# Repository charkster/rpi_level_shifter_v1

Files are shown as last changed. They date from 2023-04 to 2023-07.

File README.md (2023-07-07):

# rpi_level_shifter_v1
Raspberry Pi level shifter for 10 signals (two boards can fit on the same 40 pin header). Two NVT2010PW ICs are available on a single board, to either level shift from 3.3V to 5V or from 3.3V to 1.8V and 1.2V (jumper selectable). The RPi's 5V is used for the 5V level shift and two on-board LDO regulators are available for shifting levels down to 1.8V or 1.2V. Other voltages can be used, but it is recommended that they not be between 2.6V and 4.3V.  

This board is designed to not fit over-top the RPi board, but rather over the side.

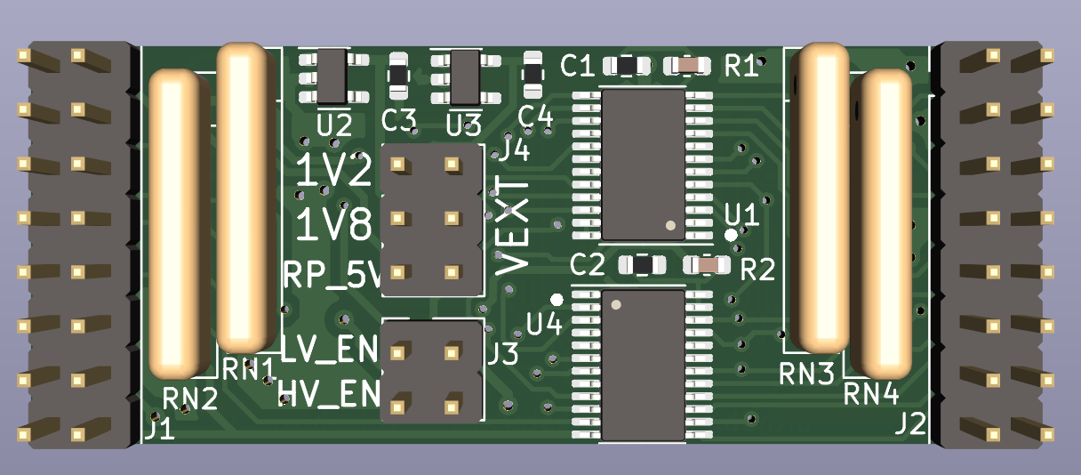
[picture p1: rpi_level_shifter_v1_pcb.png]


Each board needs to have the top-left pin of J1 connected to the 3.3V RPi header pin. One board can service the I2C and UART pins (along with a couple of GPIO) and another board can service SPI pins. BCM GPIO's 13, 16, 19, 20, 21 and 26 are not accessable with this board.

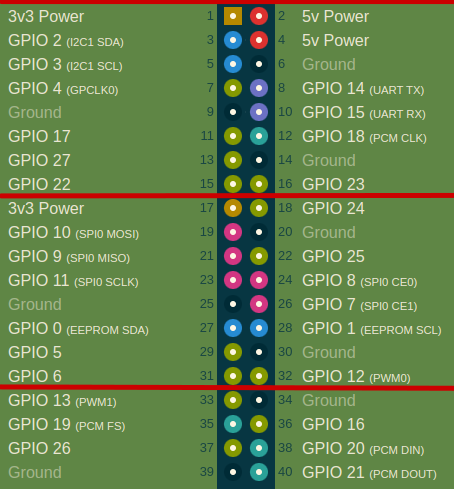
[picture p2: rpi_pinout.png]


Check-out my **PDF** [schematic](https://github.com/charkster/rpi_level_shifter_v1/blob/main/rpi_8x2_v1.pdf) !!

Check-out the CSV [**Bill of Materials**](https://github.com/charkster/rpi_level_shifter_v1/blob/main/rpi_8x2_v1_BOM.csv) !!

**The J3 connector must only have one horizontal jumper!! Either HV_EN or LV_EN, or damage to the RPi pins may occur (you have been warned). Additionally, the J4 connector must only have one horizontal jumper!! The RPI_5V is only available if the level shifter board is at the top of the header, otherwise you will need to jumper wire the 5V to the VEXT pin.**

**UPDATES:**
SPI at 5V is working well to 10MHz with the 1k Ohm pull-up resistors. This matches nicely with the NVT2010PW datasheet. I lowered the pull-up resistors to 500 Ohm and was able to get SPI working at 12MHz. I was not able to run faster than 12MHz at 5V. Power consumption was about 0.5W for both the 0.5k and 1k pull-up resistors.

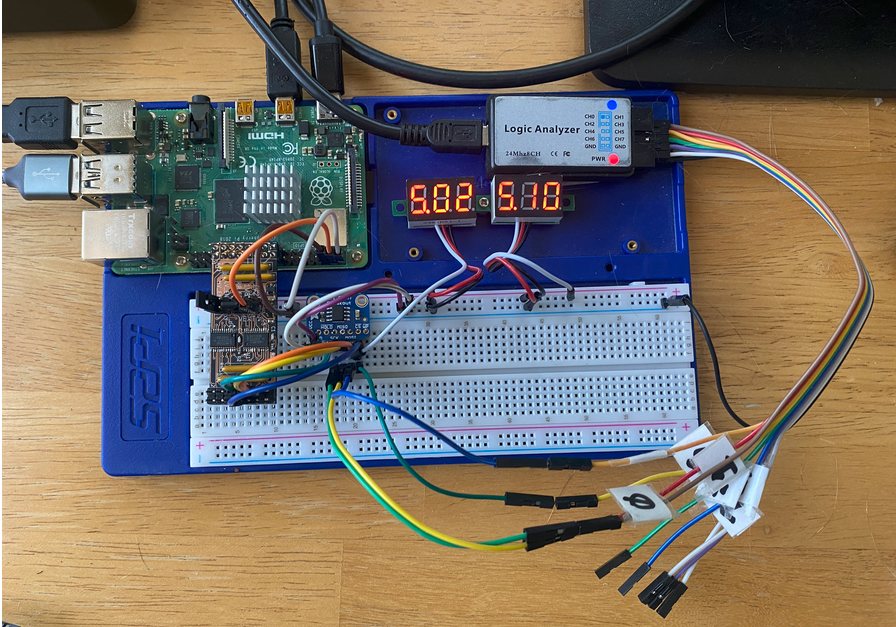
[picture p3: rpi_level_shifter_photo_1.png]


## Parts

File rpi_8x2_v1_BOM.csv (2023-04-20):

Source: | rpi_8x2_v1.kicad_sch
Date: | Wed 19 Apr 2023 10:41:58 PM MST
Tool: | Eeschema 6.0.2+dfsg-1
Generator: | /usr/share/kicad/plugins/bom_csv_grouped_by_value.py
Component Count: | 18
Individual Components:
Item | Qty | Reference(s) | Value | LibPart | Footprint | Datasheet
 |  | C1 | 100pF | Device:C | Resistor_SMD:R_0603_1608Metric | ~
 |  | C2 | 100pF | Device:C | Resistor_SMD:R_0603_1608Metric | ~
 |  | C3 | 10uF | Device:C | Resistor_SMD:R_0603_1608Metric | ~
 |  | C4 | 10uF | Device:C | Resistor_SMD:R_0603_1608Metric | ~
 |  | J1 | Conn_02x08_Odd_Even | Connector_Generic:Conn_02x08_Odd_Even | Connector_PinHeader_2.54mm:PinHeader_2x08_P2.54mm_Vertical | ~
 |  | J2 | Conn_02x08_Odd_Even | Connector_Generic:Conn_02x08_Odd_Even | Connector_PinHeader_2.54mm:PinHeader_2x08_P2.54mm_Vertical | ~
 |  | J3 | Conn_02x02_Odd_Even | Connector_Generic:Conn_02x02_Odd_Even | Connector_PinHeader_2.54mm:PinHeader_2x02_P2.54mm_Vertical | ~
 |  | J4 | Conn_02x03_Odd_Even | Connector_Generic:Conn_02x03_Odd_Even | Connector_PinHeader_2.54mm:PinHeader_2x03_P2.54mm_Vertical | ~
 |  | R1 | 200k | Device:R | Capacitor_SMD:C_0603_1608Metric | ~
 |  | R2 | 200k | Device:R | Capacitor_SMD:C_0603_1608Metric | ~
 |  | RN1 | 4606X-101-102LF | Device:R_Network05 | Resistor_THT:R_Array_SIP6 | https://www.mouser.com/datasheet/2/54/4600x-776645.pdf
 |  | RN2 | 4606X-101-102LF | Device:R_Network05 | Resistor_THT:R_Array_SIP6 | https://www.mouser.com/datasheet/2/54/4600x-776645.pdf
 |  | RN3 | 4606X-101-102LF | Device:R_Network05 | Resistor_THT:R_Array_SIP6 | https://www.mouser.com/datasheet/2/54/4600x-776645.pdf
 |  | RN4 | 4606X-101-102LF | Device:R_Network05 | Resistor_THT:R_Array_SIP6 | https://www.mouser.com/datasheet/2/54/4600x-776645.pdf
 |  | U1 | NVT2010PW | rpi_8x2_v1:NVT2010PW | Package_SO:TSSOP-24_4.4x7.8mm_P0.65mm | https://www.nxp.com/docs/en/data-sheet/NVT2008_NVT2010.pdf
 |  | U2 | AP2112K-1.8 | Regulator_Linear:AP2112K-1.8 | Package_TO_SOT_SMD:SOT-23-5 | https://www.diodes.com/assets/Datasheets/AP2112.pdf
 |  | U3 | AP2112K-1.2 | Regulator_Linear:AP2112K-1.2 | Package_TO_SOT_SMD:SOT-23-5 | https://www.diodes.com/assets/Datasheets/AP2112.pdf
 |  | U4 | NVT2010PW | rpi_8x2_v1:NVT2010PW | Package_SO:TSSOP-24_4.4x7.8mm_P0.65mm | https://www.nxp.com/docs/en/data-sheet/NVT2008_NVT2010.pdf
Collated Components:
Item | Qty | Reference(s) | Value | LibPart | Footprint | Datasheet
1 | 2 | C1, C2 | 100pF | Device:C | Resistor_SMD:R_0603_1608Metric | ~
2 | 2 | C3, C4 | 10uF | Device:C | Resistor_SMD:R_0603_1608Metric | ~
3 | 2 | J1, J2 | Conn_02x08_Odd_Even | Connector_Generic:Conn_02x08_Odd_Even | Connector_PinHeader_2.54mm:PinHeader_2x08_P2.54mm_Vertical | ~
4 | 1 | J3 | Conn_02x02_Odd_Even | Connector_Generic:Conn_02x02_Odd_Even | Connector_PinHeader_2.54mm:PinHeader_2x02_P2.54mm_Vertical | ~
5 | 1 | J4 | Conn_02x03_Odd_Even | Connector_Generic:Conn_02x03_Odd_Even | Connector_PinHeader_2.54mm:PinHeader_2x03_P2.54mm_Vertical | ~
6 | 2 | R1, R2 | 200k | Device:R | Capacitor_SMD:C_0603_1608Metric | ~
7 | 4 | RN1, RN2, RN3, RN4 | 4606X-101-102LF | Device:R_Network05 | Resistor_THT:R_Array_SIP6 | https://www.mouser.com/datasheet/2/54/4600x-776645.pdf
8 | 2 | U1, U4 | NVT2010PW | rpi_8x2_v1:NVT2010PW | Package_SO:TSSOP-24_4.4x7.8mm_P0.65mm | https://www.nxp.com/docs/en/data-sheet/NVT2008_NVT2010.pdf
9 | 1 | U2 | AP2112K-1.8 | Regulator_Linear:AP2112K-1.8 | Package_TO_SOT_SMD:SOT-23-5 | https://www.diodes.com/assets/Datasheets/AP2112.pdf
10 | 1 | U3 | AP2112K-1.2 | Regulator_Linear:AP2112K-1.2 | Package_TO_SOT_SMD:SOT-23-5 | https://www.diodes.com/assets/Datasheets/AP2112.pdf

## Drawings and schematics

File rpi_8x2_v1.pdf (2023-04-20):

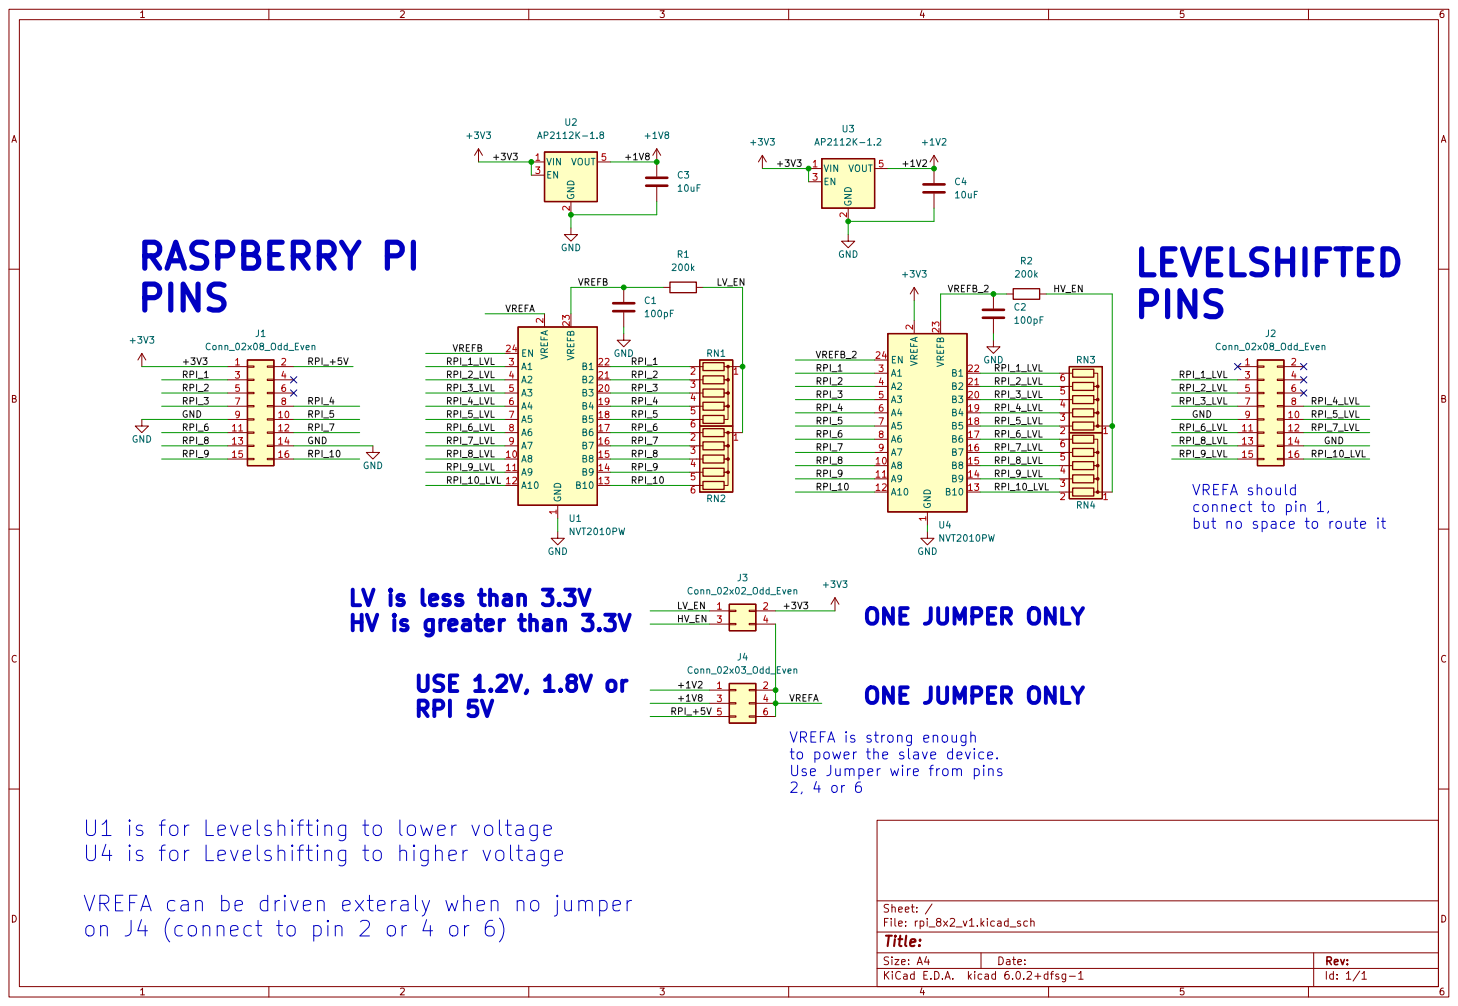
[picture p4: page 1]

VREFA should
connect to pin 1,
but no space to route it

LV is less than 3.3V
HV is greater than 3.3V

VREFA is strong enough
to power the slave device.
Use Jumper wire from pins

U1 is for Levelshifting to lower voltage
U4 is for Levelshifting to higher voltage

VREFA can be driven exteraly when no jumper
on J4 (connect to pin 2 or 4 or 6)

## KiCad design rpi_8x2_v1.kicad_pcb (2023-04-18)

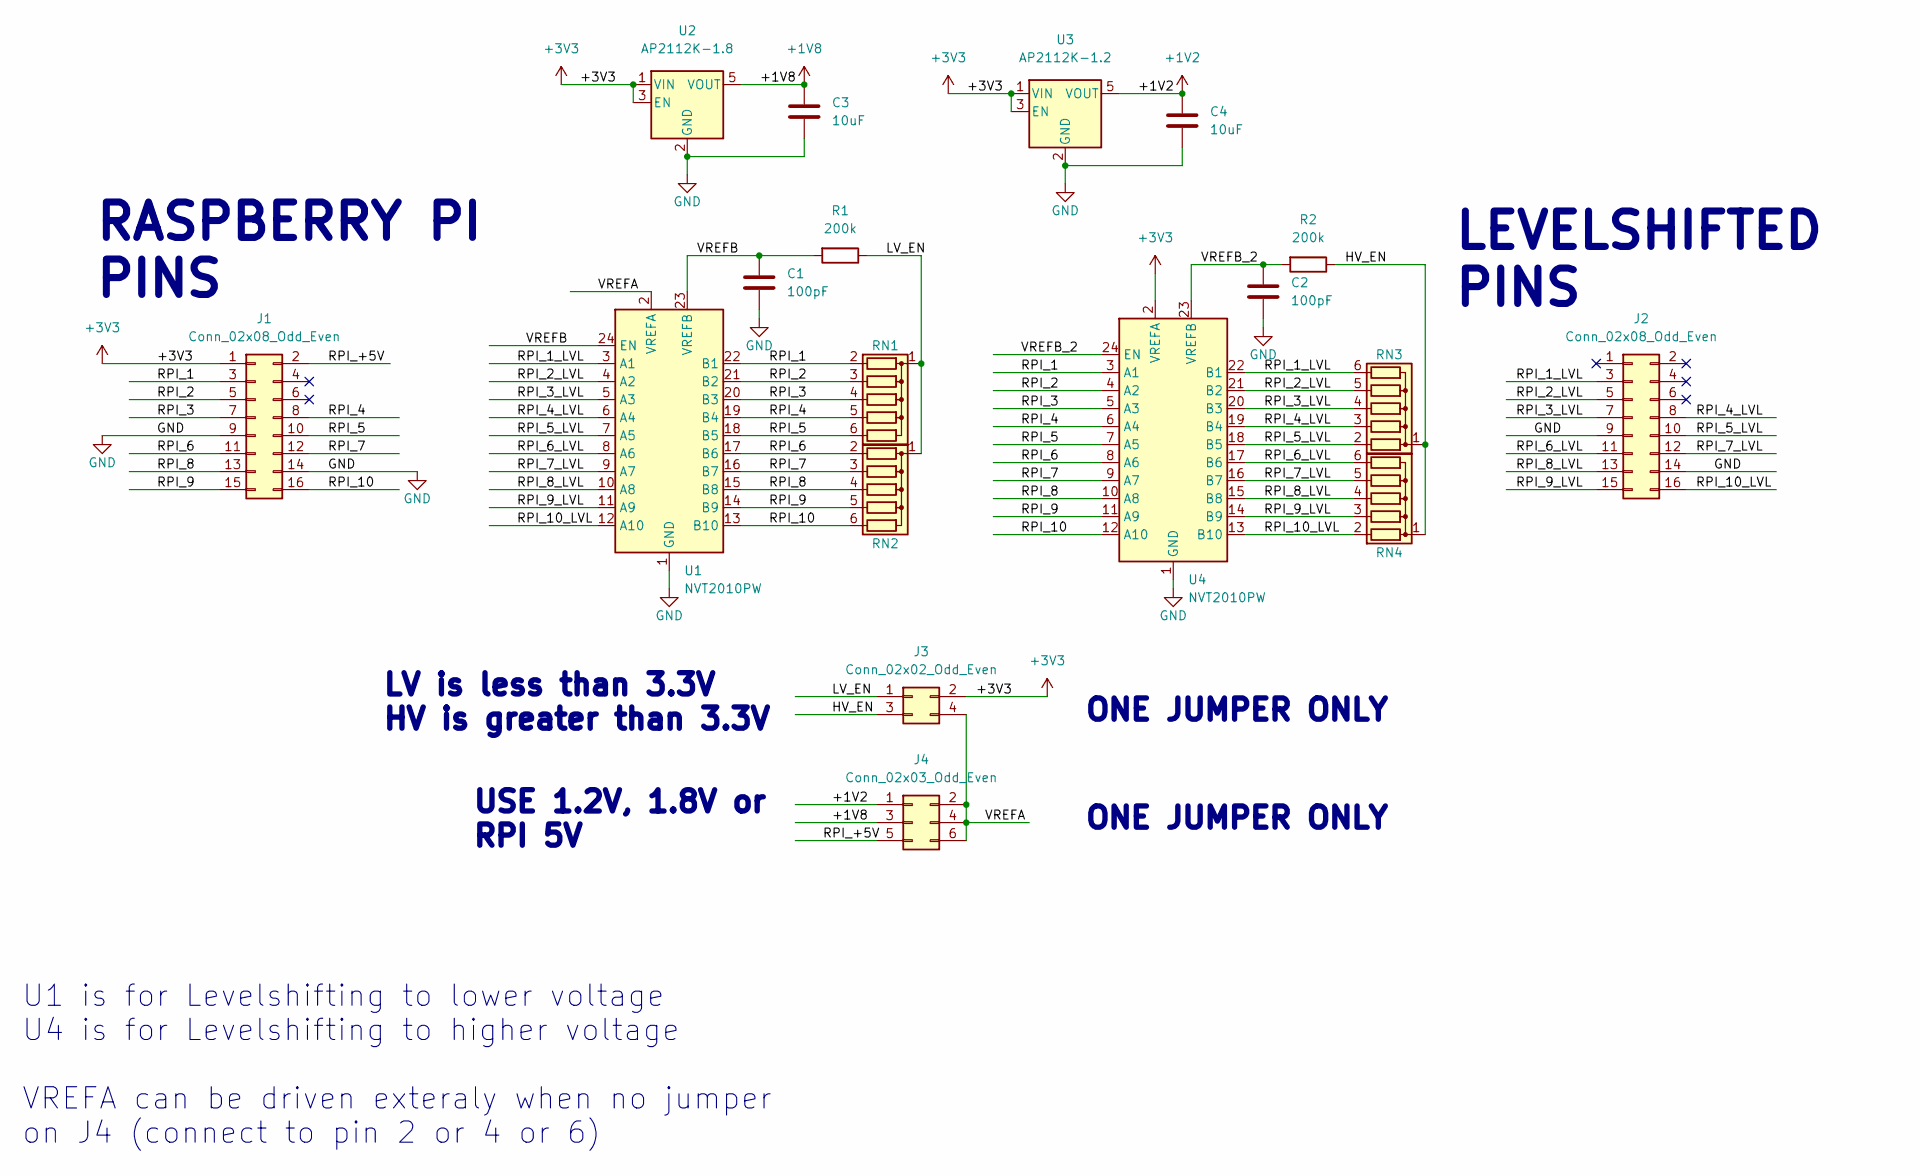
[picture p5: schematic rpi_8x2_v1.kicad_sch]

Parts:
C1, C2: 100pF; R_0603_1608Metric
C3, C4: 10uF; R_0603_1608Metric
J1, J2: Conn_02x08_Odd_Even; PinHeader_2x08_P2.54mm_Vertical
J3: Conn_02x02_Odd_Even; PinHeader_2x02_P2.54mm_Vertical
J4: Conn_02x03_Odd_Even; PinHeader_2x03_P2.54mm_Vertical
R1, R2: 200k; C_0603_1608Metric
RN1, RN2, RN3, RN4: R_Network05; R_Array_SIP6
U1, U4: NVT2010PW; TSSOP-24_4.4x7.8mm_P0.65mm
U2: AP2112K-1.8; SOT-23-5
U3: AP2112K-1.2; SOT-23-5

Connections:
+1V2: C4.1, J4.1, U3.5 (VOUT)
+1V8: C3.1, J4.3, U2.5 (VOUT)
+3V3: J1.1, J3.2, U2.1 (VIN), U2.3 (EN), U3.1 (VIN), U3.3 (EN), U4.2 (VREFA)
/HV_EN: J3.3, R2.1, RN3.1 (common), RN4.1 (common)
/LV_EN: J3.1, R1.1, RN1.1 (common), RN2.1 (common)
/RPI_1: J1.3, RN1.2 (R1), U1.22 (B1), U4.3 (A1)
/RPI_1_LVL: J2.3, RN3.6 (R5), U1.3 (A1), U4.22 (B1)
/RPI_2: J1.5, RN1.3 (R2), U1.21 (B2), U4.4 (A2)
/RPI_2_LVL: J2.5, RN3.5 (R4), U1.4 (A2), U4.21 (B2)
/RPI_3: J1.7, RN1.4 (R3), U1.20 (B3), U4.5 (A3)
/RPI_3_LVL: J2.7, RN3.4 (R3), U1.5 (A3), U4.20 (B3)
/RPI_4: J1.8, RN1.5 (R4), U1.19 (B4), U4.6 (A4)
/RPI_4_LVL: J2.8, RN3.3 (R2), U1.6 (A4), U4.19 (B4)
/RPI_5: J1.10, RN1.6 (R5), U1.18 (B5), U4.7 (A5)
/RPI_5_LVL: J2.10, RN3.2 (R1), U1.7 (A5), U4.18 (B5)
/RPI_6: J1.11, RN2.2 (R1), U1.17 (B6), U4.8 (A6)
/RPI_6_LVL: J2.11, RN4.6 (R5), U1.8 (A6), U4.17 (B6)
/RPI_7: J1.12, RN2.3 (R2), U1.16 (B7), U4.9 (A7)
/RPI_7_LVL: J2.12, RN4.5 (R4), U1.9 (A7), U4.16 (B7)
/RPI_8: J1.13, RN2.4 (R3), U1.15 (B8), U4.10 (A8)
/RPI_8_LVL: J2.13, RN4.4 (R3), U1.10 (A8), U4.15 (B8)
/RPI_9: J1.15, RN2.5 (R4), U1.14 (B9), U4.11 (A9)
/RPI_9_LVL: J2.15, RN4.3 (R2), U1.11 (A9), U4.14 (B9)
/RPI_10: J1.16, RN2.6 (R5), U1.13 (B10), U4.12 (A10)
/RPI_10_LVL: J2.16, RN4.2 (R1), U1.12 (A10), U4.13 (B10)
/RPI_+5V: J1.2, J4.5
/VREFA: J3.4, J4.2, J4.4, J4.6, U1.2 (VREFA)
/VREFB: C1.1, R1.2, U1.23 (VREFB), U1.24 (EN)
/VREFB_2: C2.1, R2.2, U4.23 (VREFB), U4.24 (EN)
GND: C1.2, C2.2, C3.2, C4.2, J1.9, J1.14, J2.9, J2.14, U1.1 (GND), U2.2 (GND), U3.2 (GND), U4.1 (GND)

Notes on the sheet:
LEVELSHIFTED PINS
ONE JUMPER ONLY
RASPBERRY PI PINS
LV is less than 3.3V HV is greater than 3.3V
U1 is for Levelshifting to lower voltage U4 is for Levelshifting to higher voltage VREFA can be driven exteraly when no jumper on J4 (connect to pin 2 or 4 or 6)
USE 1.2V, 1.8V or RPI 5V

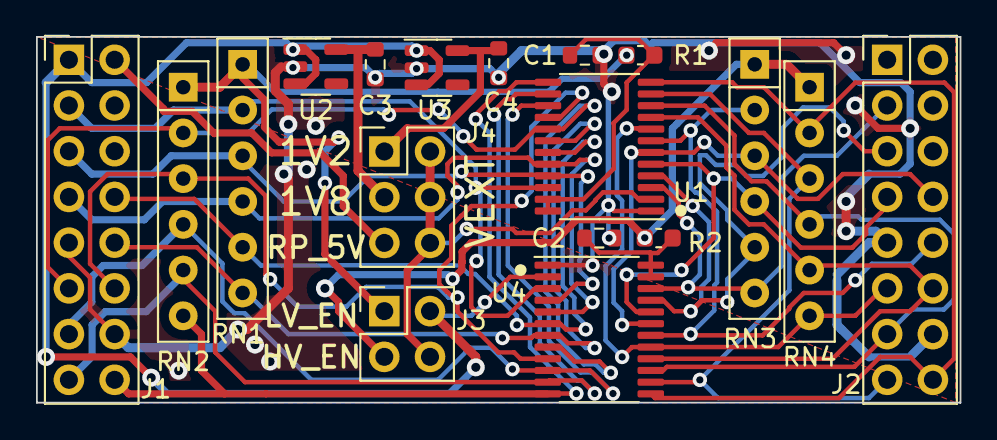
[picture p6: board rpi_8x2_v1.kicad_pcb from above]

Board: 2 copper layers, 51.3 x 20.3 mm, 18 parts (0 on the bottom side), 30 nets.
